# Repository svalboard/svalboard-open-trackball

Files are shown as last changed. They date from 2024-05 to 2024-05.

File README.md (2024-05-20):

The Svalboard Open Trackball design builds on the SideraKB PMW3360 design to make it more compact and usable for any trackball application.
This is the bare minimum footprint achievable in a single-sided SMT assembly ready to receive hand-soldered PMW3389/60 parts -- it is intended to be ordered direct from JLCPCB, fully assembled except for the PMW part, which you'll need to source and hand solder.

Note that in this design 3389 is the default sensor -- you need to cut and bridge the jumper for PMW3360.
Turns out PMW3389 is cheaper to buy on Aliexpress anyway... :D

By trimming lenses to match the footprint, you can fit these sensors in places previously not possible.
Because they're derived from the SideraKB version, these PCBAs are released under CERN OHL 2P, a permissive open hardware license.
I don't want to restrict what you do in any way, but since Sidera used this license, its terms still apply.

No support is offered for this design, please don't bug me (:

Note: May 20, 2024
The Svalboard Open Trackball Onshape repo is permalinked at www.svalboard.com/trackball-repo
Feel free to copy that repo and use it for whatever you like.
It will eventually include CAD for trackballs using this PCBA -- currently WIP.

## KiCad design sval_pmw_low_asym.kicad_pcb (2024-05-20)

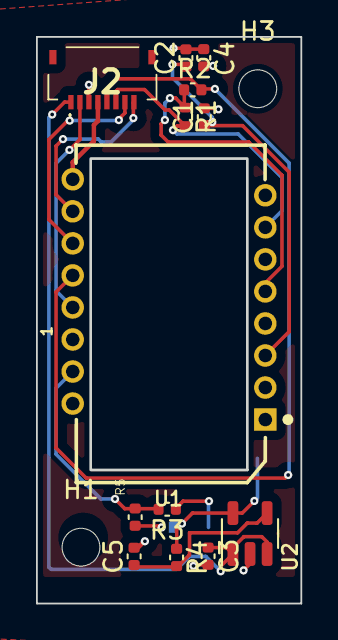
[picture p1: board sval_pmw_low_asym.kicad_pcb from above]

Board: 4 copper layers, 14.7 x 31.5 mm, 16 parts (1 on the bottom side), 15 nets.

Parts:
C1: 4.7uF/10V; C_0402_1005Metric
C2: 100nF; C_0402_1005Metric
C3, C4: 1uF; C_0402_1005Metric
C5: 22nF; C_0402_1005Metric
H1, H3: MountingHole_Pad; MountingHole_2.1mm
J2: Conn_01x08; FH34SRJ8S05SH50
JP2: SolderJumper_3_Bridged12; SolderJumper-3_P1.3mm_Bridged12_RoundedPad1.0x1.5mm_NumberL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
R1: 10k; R_0402_1005Metric
R2: 10k; C_0402_1005Metric
R3: 39R; C_0402_1005Metric
R4: 28k; C_0402_1005Metric
R5: 13R; C_0402_1005Metric
U1: PMW3360; PMW3360DM-T2QU 16Pin
U2: TLV74318PDBVR; SOT-23-5

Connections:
/CS: J2.2, U1.13 (~CS)
/MISO: J2.5, R2.2, U1.12 (MISO)
/MOSI: J2.7, U1.11 (MOSI)
/MOTION: J2.4, U1.9 (MOTION)
/RESET: J2.6, R1.2, U1.7 (~RESET)
/SCLK: J2.8, U1.10 (SCLK)
GND: C1.2, C2.2, C3.2, C4.2, C5.2, J2.3, U1.8 (GND), U2.2 (GND)
unnamed: JP2.1 (A), R5.2
unnamed: JP2.3 (B), R3.1
unnamed: R3.2, R5.1, U1.15 (LED_P)
unnamed: C1.1, C2.1, U1.3 (VDDPIX)
unnamed: C5.1, R4.2, U2.4 (NC)
VDD: C4.1, JP2.2 (C), R4.1, U1.4 (VDD), U2.5 (OUT)
V_{IN}: C3.1, J2.1, U2.1 (IN), U2.3 (EN)
V_{IO}: R1.1, R2.1, U1.5 (VDDIO)

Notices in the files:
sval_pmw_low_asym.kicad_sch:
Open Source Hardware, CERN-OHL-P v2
